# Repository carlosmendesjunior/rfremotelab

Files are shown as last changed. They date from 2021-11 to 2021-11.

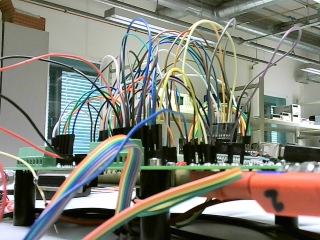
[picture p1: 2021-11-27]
Software/Octave GUI/Figures/frame.png

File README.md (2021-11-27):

# rfremotelab
**RF Remote Laboratory - ReLab**

This is a result of the post-doc of Carlos Mendes Jr. with the research assistance of Lino Van Mulken supported by Rainier van Dommele and idealized by Peter Baltus, all from Eindhoven University of Technology, The Netherlands.

We all hope that this work can help others around the world to disseminate RF laboratory experience among their students from university, college, or school.

We also welcome contributions from everyone! :)

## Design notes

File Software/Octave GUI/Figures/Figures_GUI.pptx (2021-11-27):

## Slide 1

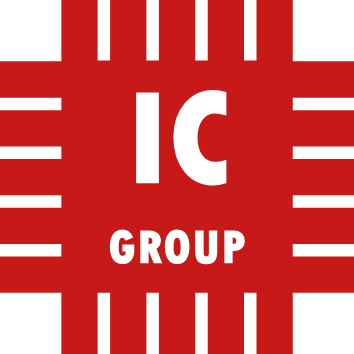
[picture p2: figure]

Figures used in the GUI

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
Integrated Circuits Group – TU/e

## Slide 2

Figures used in the GUI

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
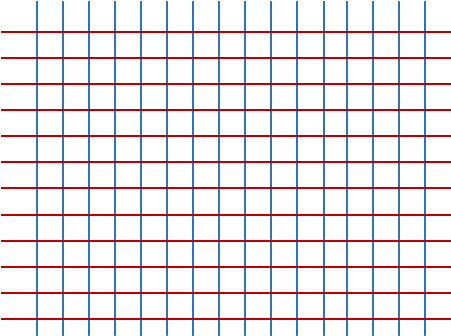
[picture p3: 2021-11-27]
Software/Octave GUI/Figures/Picture1.bmp

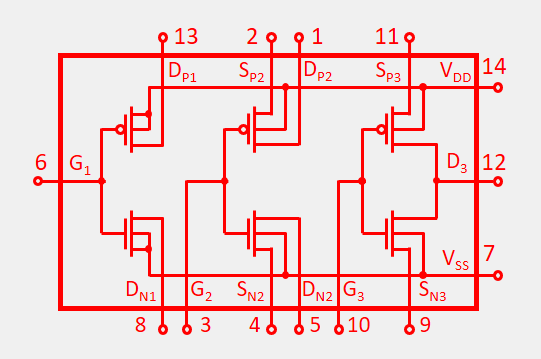
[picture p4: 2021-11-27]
Software/Octave GUI/Figures/CD4007.bmp

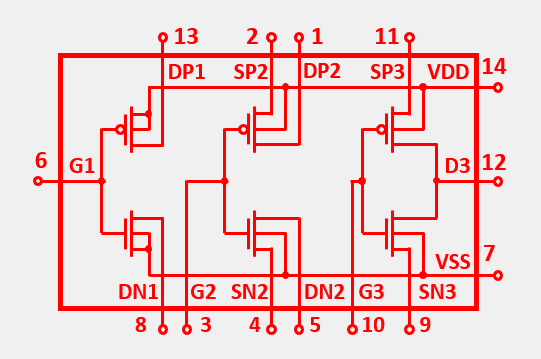
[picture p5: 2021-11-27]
Software/Octave GUI/Figures/CD4007.png

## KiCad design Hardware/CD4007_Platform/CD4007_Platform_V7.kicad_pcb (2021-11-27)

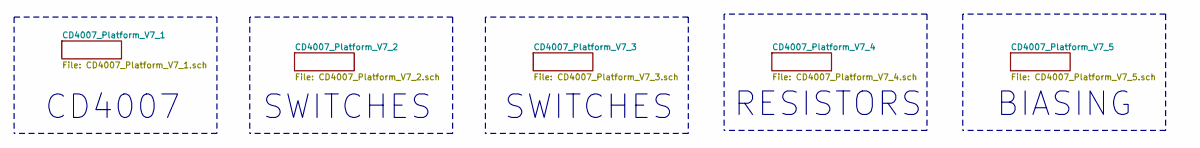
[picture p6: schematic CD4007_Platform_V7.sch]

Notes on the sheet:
CD4007
SWITCHES
SWITCHES
RESISTORS
BIASING

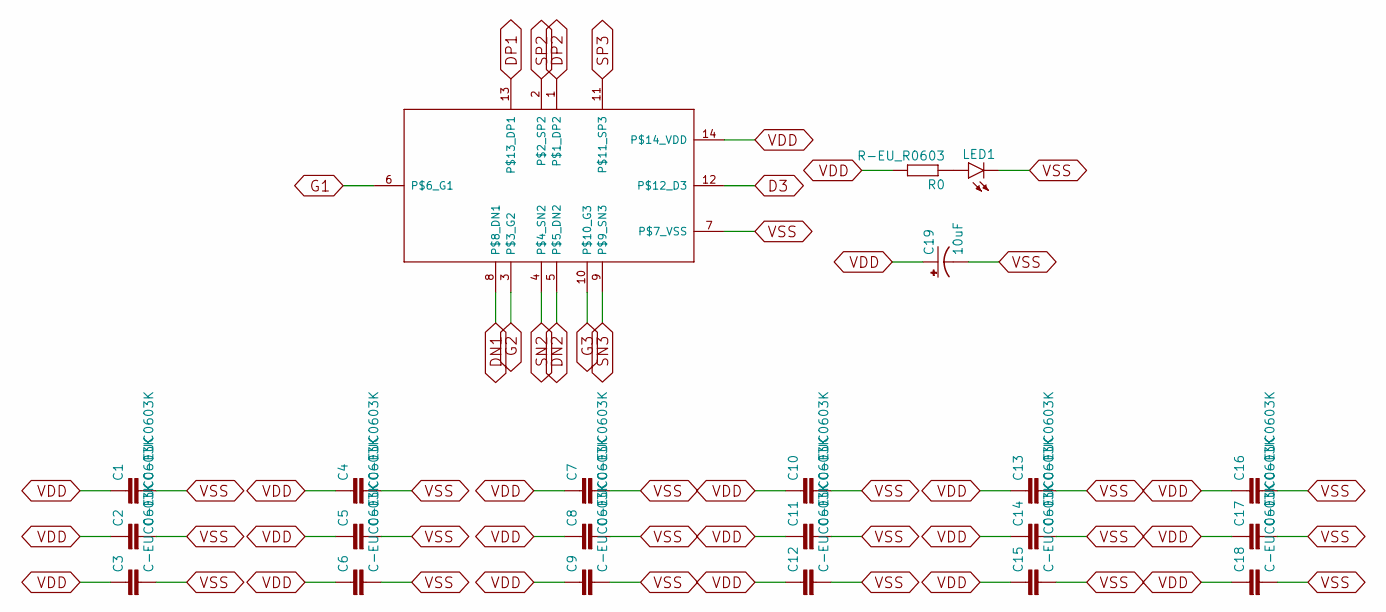
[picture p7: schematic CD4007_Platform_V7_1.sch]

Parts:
C1, C2, C3, C4, C5, C6, C7, C8, C9, C10, C11, C12, C13, C14, C15, C16, C17, C18: C-EUC0603K; C0603K
C19: 10uF; EIA3216
LED1: _T679-?-1E1F1; PLCC2
R0: R-EU_R0603; R0603
U333: CD4007; TSSOP14

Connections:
D3: U333.12 (P$12_D3); also elsewhere on the board
DN1: U333.8 (P$8_DN1); also elsewhere on the board
DN2: U333.5 (P$5_DN2); also elsewhere on the board
DP1: U333.13 (P$13_DP1); also elsewhere on the board
DP2: U333.1 (P$1_DP2); also elsewhere on the board
G1: U333.6 (P$6_G1); also elsewhere on the board
G2: U333.3 (P$3_G2); also elsewhere on the board
G3: U333.10 (P$10_G3); also elsewhere on the board
unnamed: LED1.A, R0.1
SN2: U333.4 (P$4_SN2); also elsewhere on the board
SN3: U333.9 (P$9_SN3); also elsewhere on the board
SP2: U333.2 (P$2_SP2); also elsewhere on the board
SP3: U333.11 (P$11_SP3); also elsewhere on the board
VDD: C1.1, C2.1, C3.1, C4.1, C5.1, C6.1, C7.1, C8.1, C9.1, C10.1, C11.1, C12.1, C13.1, C14.1, C15.1, C16.1, C17.1, C18.1, C19.A (+), R0.2, U333.14 (P$14_VDD); also elsewhere on the board
VSS: C1.2, C2.2, C3.2, C4.2, C5.2, C6.2, C7.2, C8.2, C9.2, C10.2, C11.2, C12.2, C13.2, C14.2, C15.2, C16.2, C17.2, C18.2, C19.C (-), LED1.C, U333.7 (P$7_VSS); also elsewhere on the board

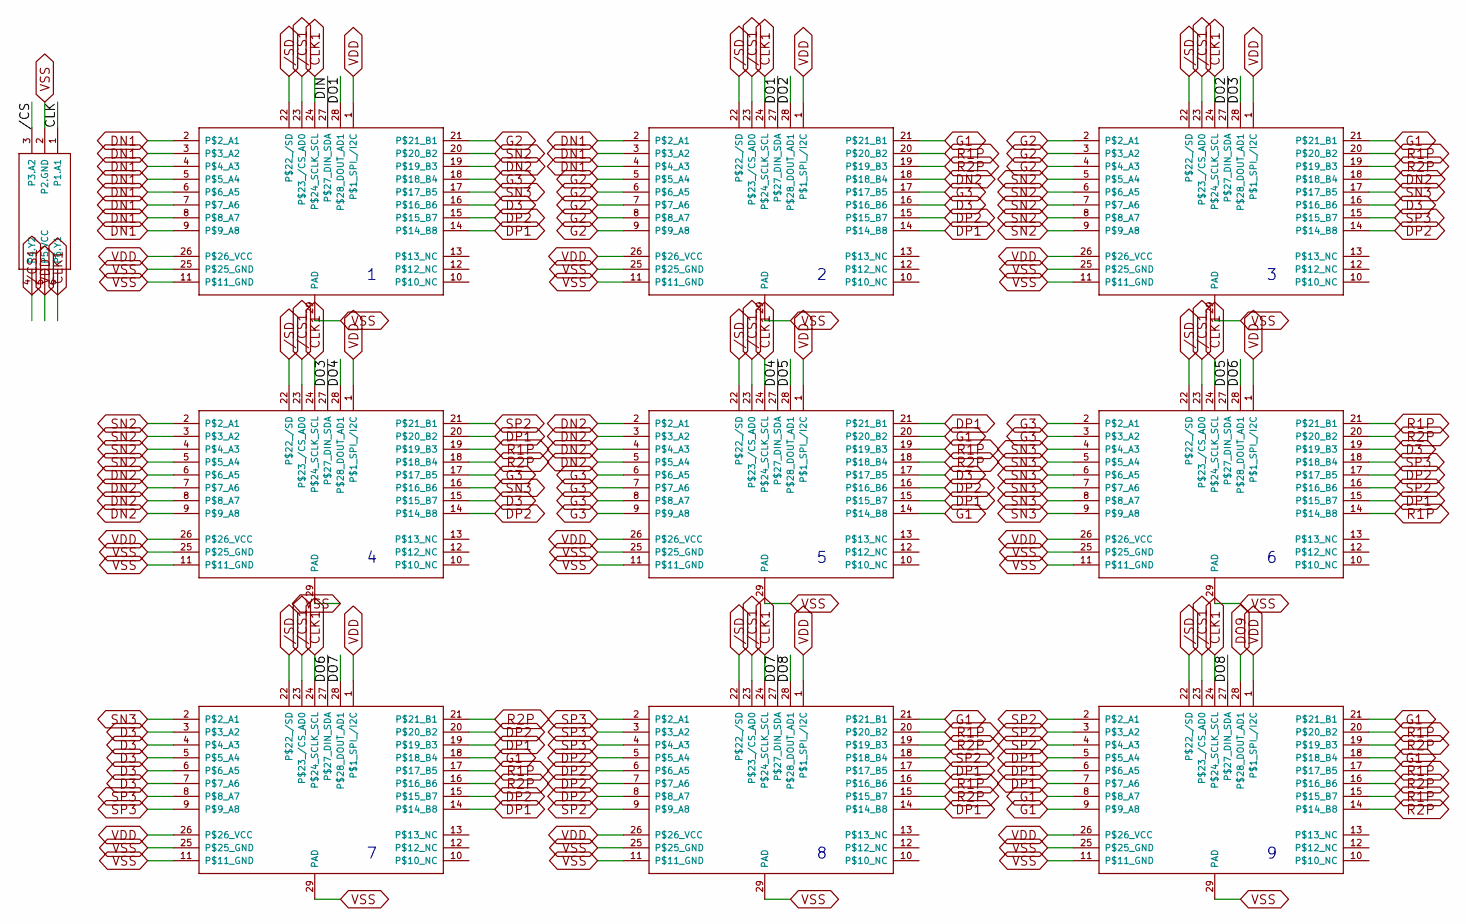
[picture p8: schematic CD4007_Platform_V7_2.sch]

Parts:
U1, U2, U3, U4, U5, U6, U7, U8, U9: MAX14662; QFN-28_UF
U110: 74LVC2G17; SOT363_PHILIPS

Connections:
/CD4007_Platform_V7_2//CS: U110.3 (P3.A2)
/CD4007_Platform_V7_2/CLK: U110.1 (P1.A1)
/CD4007_Platform_V7_2/DIN: U1.27 (P$27_DIN_SDA)
/CD4007_Platform_V7_2/DO1: U1.28 (P$28_DOUT_AD1), U2.27 (P$27_DIN_SDA)
/CD4007_Platform_V7_2/DO2: U2.28 (P$28_DOUT_AD1), U3.27 (P$27_DIN_SDA)
/CD4007_Platform_V7_2/DO3: U3.28 (P$28_DOUT_AD1), U4.27 (P$27_DIN_SDA)
/CD4007_Platform_V7_2/DO4: U4.28 (P$28_DOUT_AD1), U5.27 (P$27_DIN_SDA)
/CD4007_Platform_V7_2/DO5: U5.28 (P$28_DOUT_AD1), U6.27 (P$27_DIN_SDA)
/CD4007_Platform_V7_2/DO6: U6.28 (P$28_DOUT_AD1), U7.27 (P$27_DIN_SDA)
/CD4007_Platform_V7_2/DO7: U7.28 (P$28_DOUT_AD1), U8.27 (P$27_DIN_SDA)
/CD4007_Platform_V7_2/DO8: U8.28 (P$28_DOUT_AD1), U9.27 (P$27_DIN_SDA)
/CS1: U1.23 (P$23_/CS_AD0), U2.23 (P$23_/CS_AD0), U3.23 (P$23_/CS_AD0), U4.23 (P$23_/CS_AD0), U5.23 (P$23_/CS_AD0), U6.23 (P$23_/CS_AD0), U7.23 (P$23_/CS_AD0), U8.23 (P$23_/CS_AD0), U9.23 (P$23_/CS_AD0), U110.4 (P4.Y2); also elsewhere on the board
/SD: U1.22 (P$22_/SD), U2.22 (P$22_/SD), U3.22 (P$22_/SD), U4.22 (P$22_/SD), U5.22 (P$22_/SD), U6.22 (P$22_/SD), U7.22 (P$22_/SD), U8.22 (P$22_/SD), U9.22 (P$22_/SD); also elsewhere on the board
CLK1: U1.24 (P$24_SCLK_SCL), U2.24 (P$24_SCLK_SCL), U3.24 (P$24_SCLK_SCL), U4.24 (P$24_SCLK_SCL), U5.24 (P$24_SCLK_SCL), U6.24 (P$24_SCLK_SCL), U7.24 (P$24_SCLK_SCL), U8.24 (P$24_SCLK_SCL), U9.24 (P$24_SCLK_SCL), U110.6 (P6.Y1); also elsewhere on the board
D3: U1.16 (P$16_B6), U2.16 (P$16_B6), U3.16 (P$16_B6), U4.15 (P$15_B7), U5.17 (P$17_B5), U6.19 (P$19_B3), U7.3 (P$3_A2), U7.4 (P$4_A3), U7.5 (P$5_A4), U7.6 (P$6_A5), U7.7 (P$7_A6); also elsewhere on the board
DN1: U1.2 (P$2_A1), U1.3 (P$3_A2), U1.4 (P$4_A3), U1.5 (P$5_A4), U1.6 (P$6_A5), U1.7 (P$7_A6), U1.8 (P$8_A7), U1.9 (P$9_A8), U2.2 (P$2_A1), U2.3 (P$3_A2), U2.4 (P$4_A3); also elsewhere on the board
DN2: U1.19 (P$19_B3), U2.18 (P$18_B4), U3.18 (P$18_B4), U4.6 (P$6_A5), U4.7 (P$7_A6), U4.8 (P$8_A7), U4.9 (P$9_A8), U5.2 (P$2_A1), U5.3 (P$3_A2), U5.4 (P$4_A3), U5.5 (P$5_A4); also elsewhere on the board
DO9: U9.28 (P$28_DOUT_AD1); also elsewhere on the board
DP1: U1.14 (P$14_B8), U2.14 (P$14_B8), U4.20 (P$20_B2), U5.15 (P$15_B7), U5.21 (P$21_B1), U6.15 (P$15_B7), U7.14 (P$14_B8), U7.19 (P$19_B3), U8.14 (P$14_B8), U8.17 (P$17_B5), U9.5 (P$5_A4), U9.6 (P$6_A5), U9.7 (P$7_A6); also elsewhere on the board
DP2: U1.15 (P$15_B7), U2.15 (P$15_B7), U3.14 (P$14_B8), U4.14 (P$14_B8), U5.16 (P$16_B6), U6.17 (P$17_B5), U7.15 (P$15_B7), U7.20 (P$20_B2), U8.5 (P$5_A4), U8.6 (P$6_A5), U8.7 (P$7_A6), U8.8 (P$8_A7); also elsewhere on the board
G1: U2.21 (P$21_B1), U3.21 (P$21_B1), U5.14 (P$14_B8), U5.20 (P$20_B2), U7.18 (P$18_B4), U8.21 (P$21_B1), U9.8 (P$8_A7), U9.9 (P$9_A8), U9.18 (P$18_B4), U9.21 (P$21_B1); also elsewhere on the board
G2: U1.21 (P$21_B1), U2.5 (P$5_A4), U2.6 (P$6_A5), U2.7 (P$7_A6), U2.8 (P$8_A7), U2.9 (P$9_A8), U3.2 (P$2_A1), U3.3 (P$3_A2), U3.4 (P$4_A3); also elsewhere on the board
G3: U1.18 (P$18_B4), U2.17 (P$17_B5), U4.17 (P$17_B5), U5.6 (P$6_A5), U5.7 (P$7_A6), U5.8 (P$8_A7), U5.9 (P$9_A8), U6.2 (P$2_A1), U6.3 (P$3_A2); also elsewhere on the board
R1P: U2.20 (P$20_B2), U3.20 (P$20_B2), U4.19 (P$19_B3), U5.19 (P$19_B3), U6.14 (P$14_B8), U6.21 (P$21_B1), U7.17 (P$17_B5), U8.16 (P$16_B6), U8.20 (P$20_B2), U9.15 (P$15_B7), U9.17 (P$17_B5), U9.20 (P$20_B2); also elsewhere on the board
R2P: U2.19 (P$19_B3), U3.19 (P$19_B3), U4.18 (P$18_B4), U5.18 (P$18_B4), U6.20 (P$20_B2), U7.16 (P$16_B6), U7.21 (P$21_B1), U8.15 (P$15_B7), U8.19 (P$19_B3), U9.14 (P$14_B8), U9.16 (P$16_B6), U9.19 (P$19_B3); also elsewhere on the board
SN2: U1.20 (P$20_B2), U3.5 (P$5_A4), U3.6 (P$6_A5), U3.7 (P$7_A6), U3.8 (P$8_A7), U3.9 (P$9_A8), U4.2 (P$2_A1), U4.3 (P$3_A2), U4.4 (P$4_A3), U4.5 (P$5_A4); also elsewhere on the board
SN3: U1.17 (P$17_B5), U3.17 (P$17_B5), U4.16 (P$16_B6), U6.4 (P$4_A3), U6.5 (P$5_A4), U6.6 (P$6_A5), U6.7 (P$7_A6), U6.8 (P$8_A7), U6.9 (P$9_A8), U7.2 (P$2_A1); also elsewhere on the board
SP2: U4.21 (P$21_B1), U6.16 (P$16_B6), U8.9 (P$9_A8), U8.18 (P$18_B4), U9.2 (P$2_A1), U9.3 (P$3_A2), U9.4 (P$4_A3); also elsewhere on the board
SP3: U3.15 (P$15_B7), U6.18 (P$18_B4), U7.8 (P$8_A7), U7.9 (P$9_A8), U8.2 (P$2_A1), U8.3 (P$3_A2), U8.4 (P$4_A3); also elsewhere on the board
VDD: U1.1 (P$1_SPI_/I2C), U1.26 (P$26_VCC), U2.1 (P$1_SPI_/I2C), U2.26 (P$26_VCC), U3.1 (P$1_SPI_/I2C), U3.26 (P$26_VCC), U4.1 (P$1_SPI_/I2C), U4.26 (P$26_VCC), U5.1 (P$1_SPI_/I2C), U5.26 (P$26_VCC), U6.1 (P$1_SPI_/I2C), U6.26 (P$26_VCC), U7.1 (P$1_SPI_/I2C), U7.26 (P$26_VCC), U8.1 (P$1_SPI_/I2C), U8.26 (P$26_VCC), U9.1 (P$1_SPI_/I2C), U9.26 (P$26_VCC), U110.5 (P5.VCC); also elsewhere on the board
VSS: U1.11 (P$11_GND), U1.25 (P$25_GND), U1.29 (PAD), U2.11 (P$11_GND), U2.25 (P$25_GND), U2.29 (PAD), U3.11 (P$11_GND), U3.25 (P$25_GND), U3.29 (PAD), U4.11 (P$11_GND), U4.25 (P$25_GND), U4.29 (PAD), U5.11 (P$11_GND), U5.25 (P$25_GND), U5.29 (PAD), U6.11 (P$11_GND), U6.25 (P$25_GND), U6.29 (PAD), U7.11 (P$11_GND), U7.25 (P$25_GND), U7.29 (PAD), U8.11 (P$11_GND), U8.25 (P$25_GND), U8.29 (PAD), U9.11 (P$11_GND), U9.25 (P$25_GND), U9.29 (PAD), U110.2 (P2.GND); also elsewhere on the board

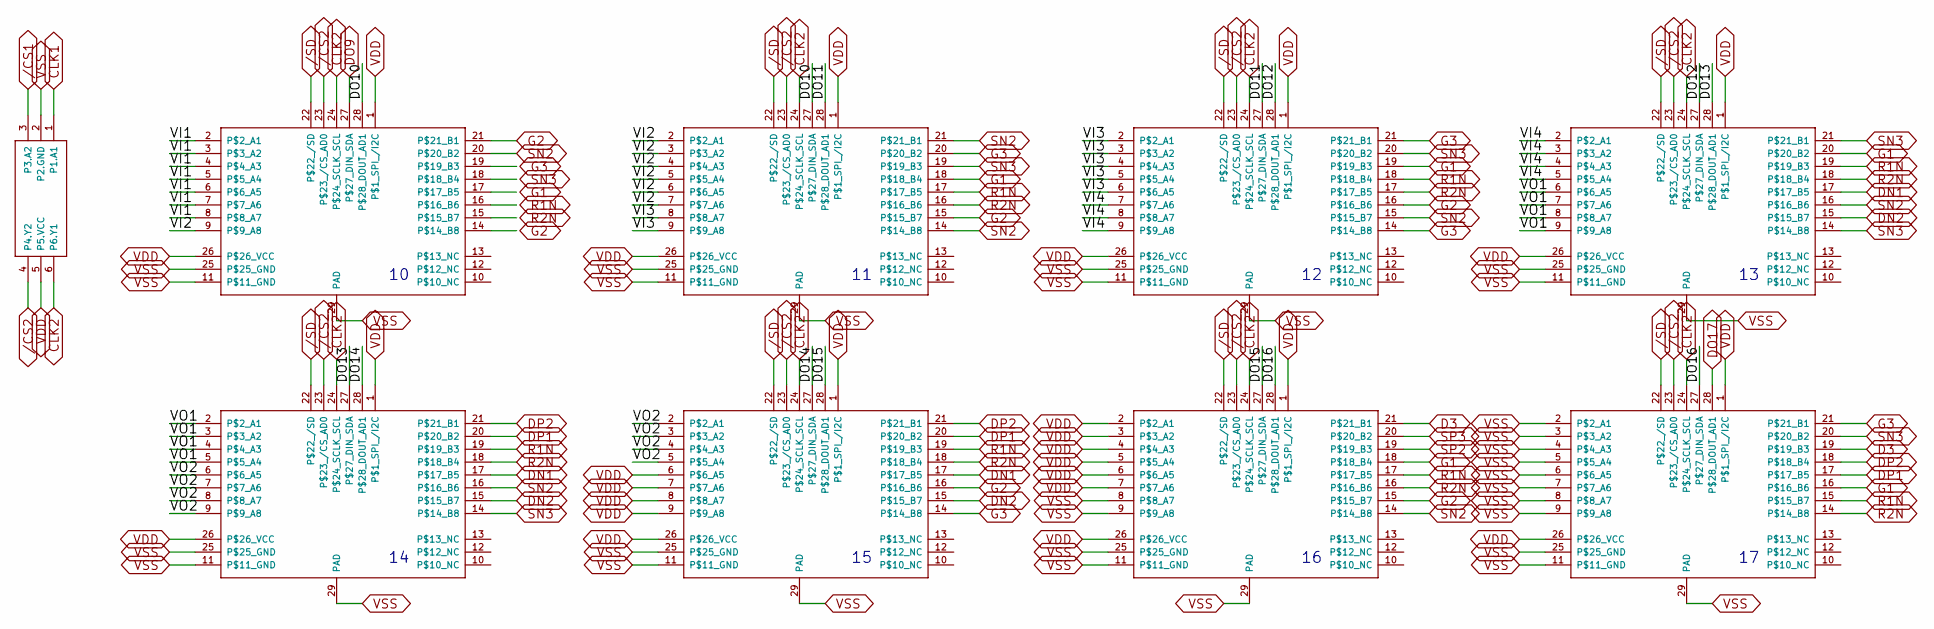
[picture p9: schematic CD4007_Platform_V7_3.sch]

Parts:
U10, U11, U12, U13, U14, U15, U16, U17: MAX14662; QFN-28_UF
U111: 74LVC2G17; SOT363_PHILIPS

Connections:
/CD4007_Platform_V7_3/DO10: U10.28 (P$28_DOUT_AD1), U11.27 (P$27_DIN_SDA)
/CD4007_Platform_V7_3/DO11: U11.28 (P$28_DOUT_AD1), U12.27 (P$27_DIN_SDA)
/CD4007_Platform_V7_3/DO12: U12.28 (P$28_DOUT_AD1), U13.27 (P$27_DIN_SDA)
/CD4007_Platform_V7_3/DO13: U13.28 (P$28_DOUT_AD1), U14.27 (P$27_DIN_SDA)
/CD4007_Platform_V7_3/DO14: U14.28 (P$28_DOUT_AD1), U15.27 (P$27_DIN_SDA)
/CD4007_Platform_V7_3/DO15: U15.28 (P$28_DOUT_AD1), U16.27 (P$27_DIN_SDA)
/CD4007_Platform_V7_3/DO16: U16.28 (P$28_DOUT_AD1), U17.27 (P$27_DIN_SDA)
/CD4007_Platform_V7_3/VI1: U10.2 (P$2_A1), U10.3 (P$3_A2), U10.4 (P$4_A3), U10.5 (P$5_A4), U10.6 (P$6_A5), U10.7 (P$7_A6), U10.8 (P$8_A7)
/CD4007_Platform_V7_3/VI2: U10.9 (P$9_A8), U11.2 (P$2_A1), U11.3 (P$3_A2), U11.4 (P$4_A3), U11.5 (P$5_A4), U11.6 (P$6_A5), U11.7 (P$7_A6)
/CD4007_Platform_V7_3/VI3: U11.8 (P$8_A7), U11.9 (P$9_A8), U12.2 (P$2_A1), U12.3 (P$3_A2), U12.4 (P$4_A3), U12.5 (P$5_A4), U12.6 (P$6_A5)
/CD4007_Platform_V7_3/VI4: U12.7 (P$7_A6), U12.8 (P$8_A7), U12.9 (P$9_A8), U13.2 (P$2_A1), U13.3 (P$3_A2), U13.4 (P$4_A3), U13.5 (P$5_A4)
/CD4007_Platform_V7_3/VO1: U13.6 (P$6_A5), U13.7 (P$7_A6), U13.8 (P$8_A7), U13.9 (P$9_A8), U14.2 (P$2_A1), U14.3 (P$3_A2), U14.4 (P$4_A3), U14.5 (P$5_A4)
/CD4007_Platform_V7_3/VO2: U14.6 (P$6_A5), U14.7 (P$7_A6), U14.8 (P$8_A7), U14.9 (P$9_A8), U15.2 (P$2_A1), U15.3 (P$3_A2), U15.4 (P$4_A3), U15.5 (P$5_A4)
/CS1: U111.3 (P3.A2); also elsewhere on the board
/CS2: U10.23 (P$23_/CS_AD0), U11.23 (P$23_/CS_AD0), U12.23 (P$23_/CS_AD0), U13.23 (P$23_/CS_AD0), U14.23 (P$23_/CS_AD0), U15.23 (P$23_/CS_AD0), U16.23 (P$23_/CS_AD0), U17.23 (P$23_/CS_AD0), U111.4 (P4.Y2); also elsewhere on the board
/SD: U10.22 (P$22_/SD), U11.22 (P$22_/SD), U12.22 (P$22_/SD), U13.22 (P$22_/SD), U14.22 (P$22_/SD), U15.22 (P$22_/SD), U16.22 (P$22_/SD), U17.22 (P$22_/SD); also elsewhere on the board
CLK1: U111.1 (P1.A1); also elsewhere on the board
CLK2: U10.24 (P$24_SCLK_SCL), U11.24 (P$24_SCLK_SCL), U12.24 (P$24_SCLK_SCL), U13.24 (P$24_SCLK_SCL), U14.24 (P$24_SCLK_SCL), U15.24 (P$24_SCLK_SCL), U16.24 (P$24_SCLK_SCL), U17.24 (P$24_SCLK_SCL), U111.6 (P6.Y1); also elsewhere on the board
D3: U16.21 (P$21_B1), U17.19 (P$19_B3); also elsewhere on the board
DN1: U13.17 (P$17_B5), U14.17 (P$17_B5), U15.17 (P$17_B5); also elsewhere on the board
DN2: U13.15 (P$15_B7), U14.15 (P$15_B7), U15.15 (P$15_B7); also elsewhere on the board
DO9: U10.27 (P$27_DIN_SDA); also elsewhere on the board
DO17: U17.28 (P$28_DOUT_AD1); also elsewhere on the board
DP1: U14.20 (P$20_B2), U15.20 (P$20_B2), U17.17 (P$17_B5); also elsewhere on the board
DP2: U14.21 (P$21_B1), U15.21 (P$21_B1), U17.18 (P$18_B4); also elsewhere on the board
G1: U10.17 (P$17_B5), U11.18 (P$18_B4), U12.19 (P$19_B3), U13.20 (P$20_B2), U16.18 (P$18_B4), U17.16 (P$16_B6); also elsewhere on the board
G2: U10.14 (P$14_B8), U10.21 (P$21_B1), U11.15 (P$15_B7), U12.16 (P$16_B6), U15.16 (P$16_B6), U16.15 (P$15_B7); also elsewhere on the board
G3: U10.19 (P$19_B3), U11.20 (P$20_B2), U12.14 (P$14_B8), U12.21 (P$21_B1), U15.14 (P$14_B8), U17.21 (P$21_B1); also elsewhere on the board
R1N: U10.16 (P$16_B6), U11.17 (P$17_B5), U12.18 (P$18_B4), U13.19 (P$19_B3), U14.19 (P$19_B3), U15.19 (P$19_B3), U16.17 (P$17_B5), U17.15 (P$15_B7); also elsewhere on the board
R2N: U10.15 (P$15_B7), U11.16 (P$16_B6), U12.17 (P$17_B5), U13.18 (P$18_B4), U14.18 (P$18_B4), U15.18 (P$18_B4), U16.16 (P$16_B6), U17.14 (P$14_B8); also elsewhere on the board
SN2: U10.20 (P$20_B2), U11.14 (P$14_B8), U11.21 (P$21_B1), U12.15 (P$15_B7), U13.16 (P$16_B6), U14.16 (P$16_B6), U16.14 (P$14_B8); also elsewhere on the board
SN3: U10.18 (P$18_B4), U11.19 (P$19_B3), U12.20 (P$20_B2), U13.14 (P$14_B8), U13.21 (P$21_B1), U14.14 (P$14_B8), U17.20 (P$20_B2); also elsewhere on the board
SP2: U16.19 (P$19_B3); also elsewhere on the board
SP3: U16.20 (P$20_B2); also elsewhere on the board
VDD: U10.1 (P$1_SPI_/I2C), U10.26 (P$26_VCC), U11.1 (P$1_SPI_/I2C), U11.26 (P$26_VCC), U12.1 (P$1_SPI_/I2C), U12.26 (P$26_VCC), U13.1 (P$1_SPI_/I2C), U13.26 (P$26_VCC), U14.1 (P$1_SPI_/I2C), U14.26 (P$26_VCC), U15.1 (P$1_SPI_/I2C), U15.6 (P$6_A5), U15.7 (P$7_A6), U15.8 (P$8_A7), U15.9 (P$9_A8), U15.26 (P$26_VCC), U16.1 (P$1_SPI_/I2C), U16.2 (P$2_A1), U16.3 (P$3_A2), U16.4 (P$4_A3), U16.5 (P$5_A4), U16.6 (P$6_A5), U16.7 (P$7_A6), U16.26 (P$26_VCC), U17.1 (P$1_SPI_/I2C), U17.26 (P$26_VCC), U111.5 (P5.VCC); also elsewhere on the board
VSS: U10.11 (P$11_GND), U10.25 (P$25_GND), U10.29 (PAD), U11.11 (P$11_GND), U11.25 (P$25_GND), U11.29 (PAD), U12.11 (P$11_GND), U12.25 (P$25_GND), U12.29 (PAD), U13.11 (P$11_GND), U13.25 (P$25_GND), U13.29 (PAD), U14.11 (P$11_GND), U14.25 (P$25_GND), U14.29 (PAD), U15.11 (P$11_GND), U15.25 (P$25_GND), U15.29 (PAD), U16.8 (P$8_A7), U16.9 (P$9_A8), U16.11 (P$11_GND), U16.25 (P$25_GND), U16.29 (PAD), U17.2 (P$2_A1), U17.3 (P$3_A2), U17.4 (P$4_A3), U17.5 (P$5_A4), U17.6 (P$6_A5), U17.7 (P$7_A6), U17.8 (P$8_A7), U17.9 (P$9_A8), U17.11 (P$11_GND), U17.25 (P$25_GND), U17.29 (PAD), U111.2 (P2.GND); also elsewhere on the board

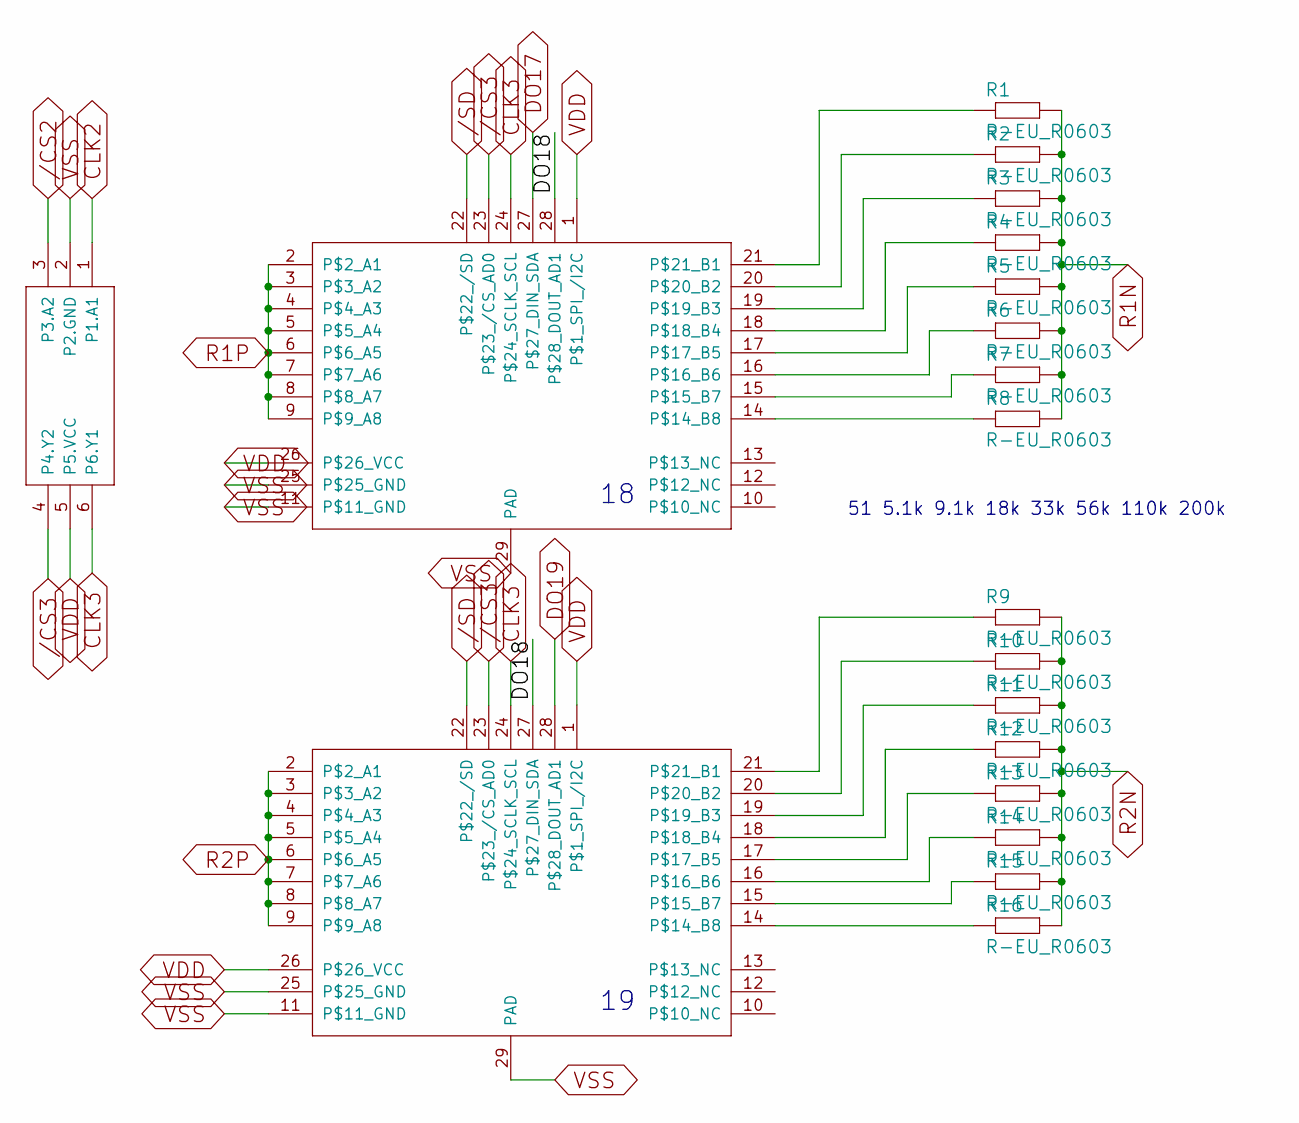
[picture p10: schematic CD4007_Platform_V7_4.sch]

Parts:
R1, R2, R3, R4, R5, R6, R7, R8, R9, R10, R11, R12, R13, R14, R15, R16: R-EU_R0603; R0603
U18, U19: MAX14662; QFN-28_UF
U112: 74LVC2G17; SOT363_PHILIPS

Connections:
/CD4007_Platform_V7_4/DO18: U18.28 (P$28_DOUT_AD1), U19.27 (P$27_DIN_SDA)
/CS2: U112.3 (P3.A2); also elsewhere on the board
/CS3: U18.23 (P$23_/CS_AD0), U19.23 (P$23_/CS_AD0), U112.4 (P4.Y2); also elsewhere on the board
/SD: U18.22 (P$22_/SD), U19.22 (P$22_/SD); also elsewhere on the board
CLK2: U112.1 (P1.A1); also elsewhere on the board
CLK3: U18.24 (P$24_SCLK_SCL), U19.24 (P$24_SCLK_SCL), U112.6 (P6.Y1); also elsewhere on the board
DO17: U18.27 (P$27_DIN_SDA); also elsewhere on the board
DO19: U19.28 (P$28_DOUT_AD1); also elsewhere on the board
unnamed: R1.1, U18.21 (P$21_B1)
unnamed: R2.1, U18.20 (P$20_B2)
unnamed: R3.1, U18.19 (P$19_B3)
unnamed: R4.1, U18.18 (P$18_B4)
unnamed: R5.1, U18.17 (P$17_B5)
unnamed: R6.1, U18.16 (P$16_B6)
unnamed: R7.1, U18.15 (P$15_B7)
unnamed: R8.1, U18.14 (P$14_B8)
unnamed: R9.1, U19.21 (P$21_B1)
unnamed: R10.1, U19.20 (P$20_B2)
unnamed: R11.1, U19.19 (P$19_B3)
unnamed: R12.1, U19.18 (P$18_B4)
unnamed: R13.1, U19.17 (P$17_B5)
unnamed: R14.1, U19.16 (P$16_B6)
unnamed: R15.1, U19.15 (P$15_B7)
unnamed: R16.1, U19.14 (P$14_B8)
R1N: R1.2, R2.2, R3.2, R4.2, R5.2, R6.2, R7.2, R8.2; also elsewhere on the board
R1P: U18.2 (P$2_A1), U18.3 (P$3_A2), U18.4 (P$4_A3), U18.5 (P$5_A4), U18.6 (P$6_A5), U18.7 (P$7_A6), U18.8 (P$8_A7), U18.9 (P$9_A8); also elsewhere on the board
R2N: R9.2, R10.2, R11.2, R12.2, R13.2, R14.2, R15.2, R16.2; also elsewhere on the board
R2P: U19.2 (P$2_A1), U19.3 (P$3_A2), U19.4 (P$4_A3), U19.5 (P$5_A4), U19.6 (P$6_A5), U19.7 (P$7_A6), U19.8 (P$8_A7), U19.9 (P$9_A8); also elsewhere on the board
VDD: U18.1 (P$1_SPI_/I2C), U18.26 (P$26_VCC), U19.1 (P$1_SPI_/I2C), U19.26 (P$26_VCC), U112.5 (P5.VCC); also elsewhere on the board
VSS: U18.11 (P$11_GND), U18.25 (P$25_GND), U18.29 (PAD), U19.11 (P$11_GND), U19.25 (P$25_GND), U19.29 (PAD), U112.2 (P2.GND); also elsewhere on the board

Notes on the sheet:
51 5.1k 9.1k 18k 33k 56k 110k 200k

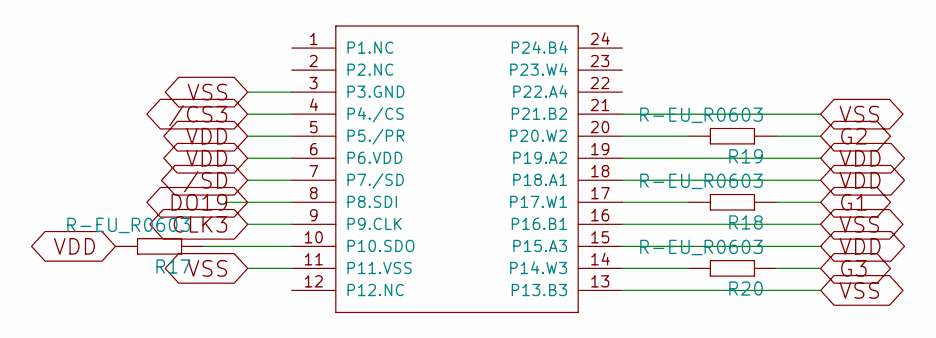
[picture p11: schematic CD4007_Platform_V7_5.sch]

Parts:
R17, R18, R19, R20: R-EU_R0603; R0603
U20: AD5204; TSSOP24

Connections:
/CS3: U20.4 (P4./CS); also elsewhere on the board
/SD: U20.7 (P7./SD); also elsewhere on the board
CLK3: U20.9 (P9.CLK); also elsewhere on the board
DO19: U20.8 (P8.SDI); also elsewhere on the board
G1: R18.1; also elsewhere on the board
G2: R19.1; also elsewhere on the board
G3: R20.1; also elsewhere on the board
unnamed: R17.1, U20.10 (P10.SDO)
unnamed: R18.2, U20.17 (P17.W1)
unnamed: R19.2, U20.20 (P20.W2)
unnamed: R20.2, U20.14 (P14.W3)
VDD: R17.2, U20.5 (P5./PR), U20.6 (P6.VDD), U20.15 (P15.A3), U20.18 (P18.A1), U20.19 (P19.A2); also elsewhere on the board
VSS: U20.3 (P3.GND), U20.11 (P11.VSS), U20.13 (P13.B3), U20.16 (P16.B1), U20.21 (P21.B2); also elsewhere on the board

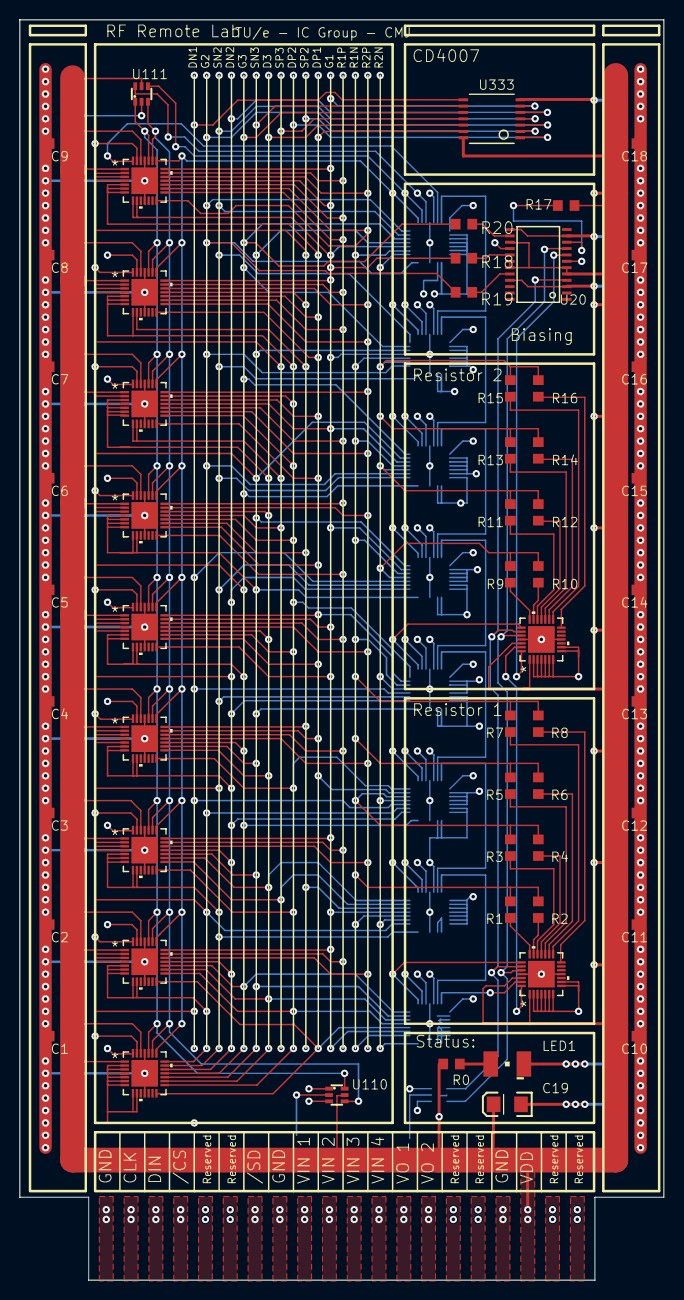
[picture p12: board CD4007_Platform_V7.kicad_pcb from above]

Board: 4 copper layers, 66.0 x 129.1 mm, 65 parts (0 on the bottom side), 71 nets.

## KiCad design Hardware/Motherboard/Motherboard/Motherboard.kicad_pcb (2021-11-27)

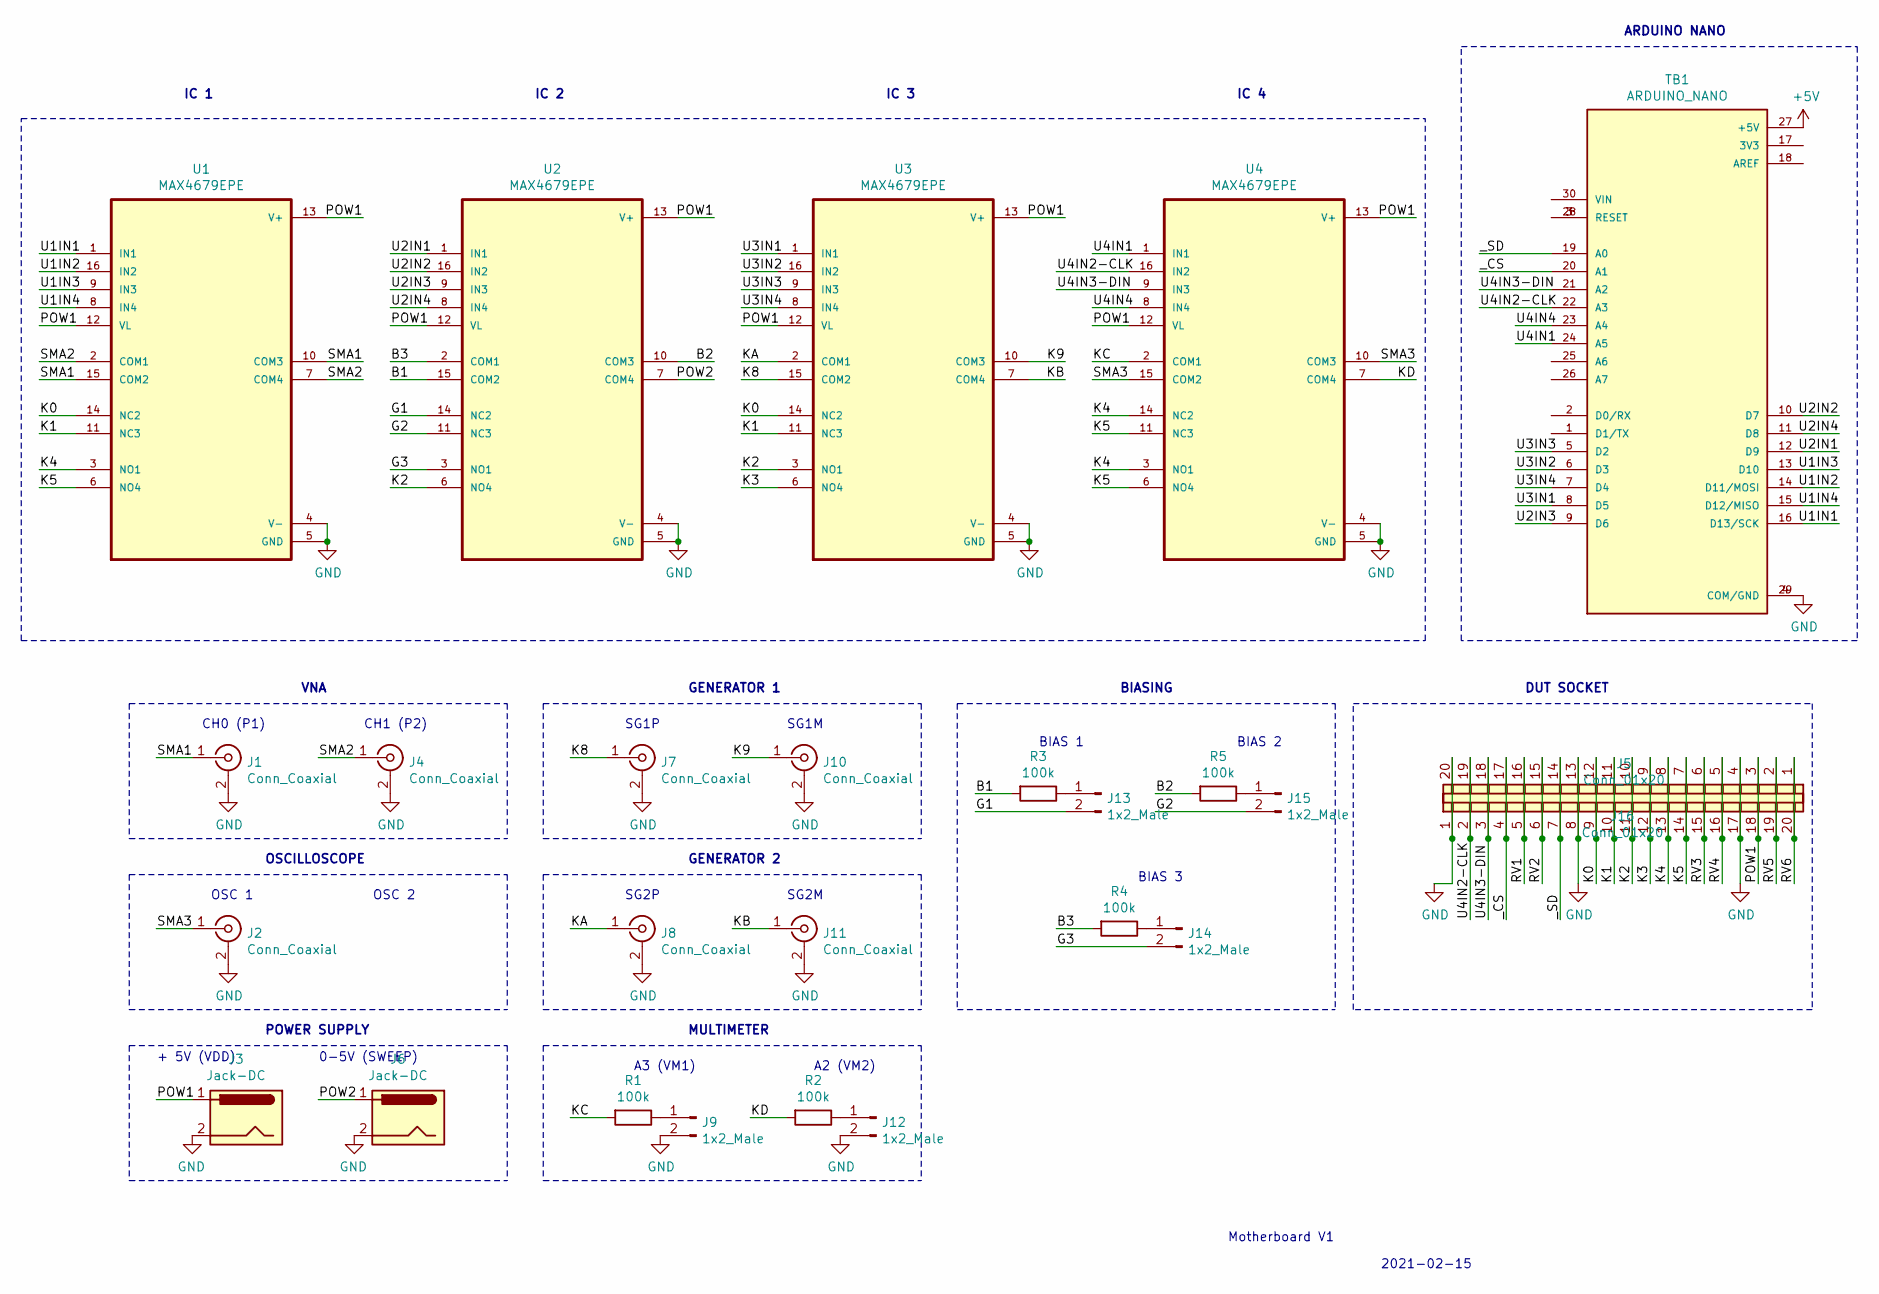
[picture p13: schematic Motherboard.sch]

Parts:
J1, J2, J4, J7, J8, J10, J11: Conn_Coaxial; SMA_Amphenol_132289_EdgeMount
J3, J6: Jack-DC; BarrelJack_Wuerth_6941xx301002
J5, J16: Conn_01x20; PinSocket_1x20_P2.54mm_Vertical
J9, J12, J13, J14, J15: 1x2_Male; PinHeader_1x02_P2.54mm_Vertical
R1, R2, R3, R4, R5: 100k; R_Axial_DIN0207_L6.3mm_D2.5mm_P10.16mm_Horizontal
TB1: ARDUINO_NANO; Arduino_Nano
U1, U2, U3, U4: MAX4679EPE; DIP-16_W7.62mm_LongPads

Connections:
+5V: TB1.27 (+5V)
/B1: R3.2, U2.15 (COM2)
/B2: R5.2, U2.10 (COM3)
/B3: R4.2, U2.2 (COM1)
/G1: J13.2, U2.14 (NC2)
/G2: J15.2, U2.11 (NC3)
/G3: J14.2, U2.3 (NO1)
/K0: J5.9, J16.12, U1.14 (NC2), U3.14 (NC2)
/K1: J5.10, J16.11, U1.11 (NC3), U3.11 (NC3)
/K2: J5.11, J16.10, U2.6 (NO4), U3.3 (NO1)
/K3: J5.12, J16.9, U3.6 (NO4)
/K4: J5.13, J16.8, U1.3 (NO1), U4.3 (NO1), U4.14 (NC2)
/K5: J5.14, J16.7, U1.6 (NO4), U4.6 (NO4), U4.11 (NC3)
/K8: J7.1 (In), U3.15 (COM2)
/K9: J10.1 (In), U3.10 (COM3)
/KA: J8.1 (In), U3.2 (COM1)
/KB: J11.1 (In), U3.7 (COM4)
/KC: R1.2, U4.2 (COM1)
/KD: R2.2, U4.7 (COM4)
/POW1: J3.1, J5.18, J16.3, U1.12 (VL), U1.13 (V+), U2.12 (VL), U2.13 (V+), U3.12 (VL), U3.13 (V+), U4.12 (VL), U4.13 (V+)
/POW2: J6.1, U2.7 (COM4)
/RV1: J5.5, J16.16
/RV2: J5.6, J16.15
/RV3: J5.15, J16.6
/RV4: J5.16, J16.5
/RV5: J5.19, J16.2
/RV6: J5.20, J16.1
/SMA1: J1.1 (In), U1.10 (COM3), U1.15 (COM2)
/SMA2: J4.1 (In), U1.2 (COM1), U1.7 (COM4)
/SMA3: J2.1 (In), U4.10 (COM3), U4.15 (COM2)
/U1IN1: TB1.16 (D13/SCK), U1.1 (IN1)
/U1IN2: TB1.14 (D11/MOSI), U1.16 (IN2)
/U1IN3: TB1.13 (D10), U1.9 (IN3)
/U1IN4: TB1.15 (D12/MISO), U1.8 (IN4)
/U2IN1: TB1.12 (D9), U2.1 (IN1)
/U2IN2: TB1.10 (D7), U2.16 (IN2)
/U2IN3: TB1.9 (D6), U2.9 (IN3)
/U2IN4: TB1.11 (D8), U2.8 (IN4)
/U3IN1: TB1.8 (D5), U3.1 (IN1)
/U3IN2: TB1.6 (D3), U3.16 (IN2)
/U3IN3: TB1.5 (D2), U3.9 (IN3)
/U3IN4: TB1.7 (D4), U3.8 (IN4)
/U4IN1: TB1.24 (A5), U4.1 (IN1)
/U4IN2-CLK: J5.2, J16.19, TB1.22 (A3), U4.16 (IN2)
/U4IN3-DIN: J5.3, J16.18, TB1.21 (A2), U4.9 (IN3)
/U4IN4: TB1.23 (A4), U4.8 (IN4)
/_CS: J5.4, J16.17, TB1.20 (A1)
/_SD: J5.7, J16.14, TB1.19 (A0)
GND: J1.2 (Ext), J2.2 (Ext), J3.2, J4.2 (Ext), J5.1, J5.8, J5.17, J6.2, J7.2 (Ext), J8.2 (Ext), J9.2, J10.2 (Ext), J11.2 (Ext), J12.2, J16.4, J16.13, J16.20, TB1.4 (COM/GND), TB1.29 (COM/GND), U1.4 (V-), U1.5 (GND), U2.4 (V-), U2.5 (GND), U3.4 (V-), U3.5 (GND), U4.4 (V-), U4.5 (GND)
unnamed: J9.1, R1.1
unnamed: J12.1, R2.1
unnamed: J13.1, R3.1
unnamed: J14.1, R4.1
unnamed: J15.1, R5.1
unnamed: TB1.3 (RESET), TB1.28 (RESET)

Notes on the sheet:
2021-02-15
Motherboard V1
VNA
CH0 (P1)
CH1 (P2)
OSCILLOSCOPE
OSC 1
OSC 2
GENERATOR 1
SG1P
SG1M
GENERATOR 2
SG2P
SG2M
MULTIMETER
A3 (VM1)
A2 (VM2)
POWER SUPPLY
+ 5V (VDD)
0-5V (SWEEP)
BIASING
ARDUINO NANO
BIAS 1
BIAS 2
BIAS 3
DUT SOCKET
IC 1
IC 2
IC 3
IC 4

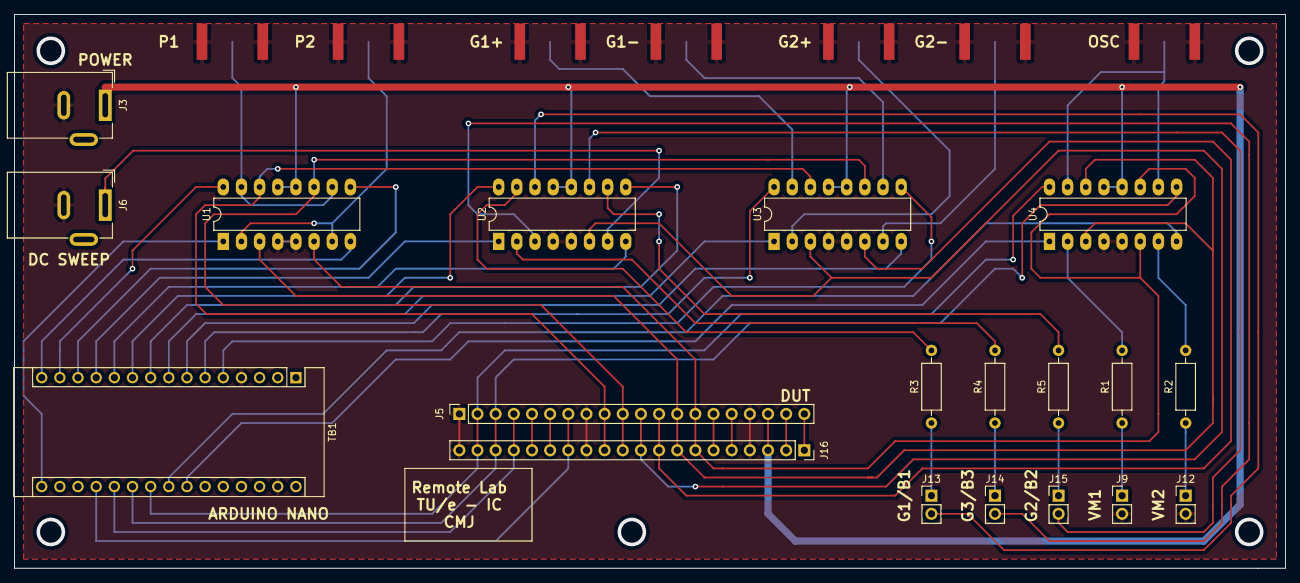
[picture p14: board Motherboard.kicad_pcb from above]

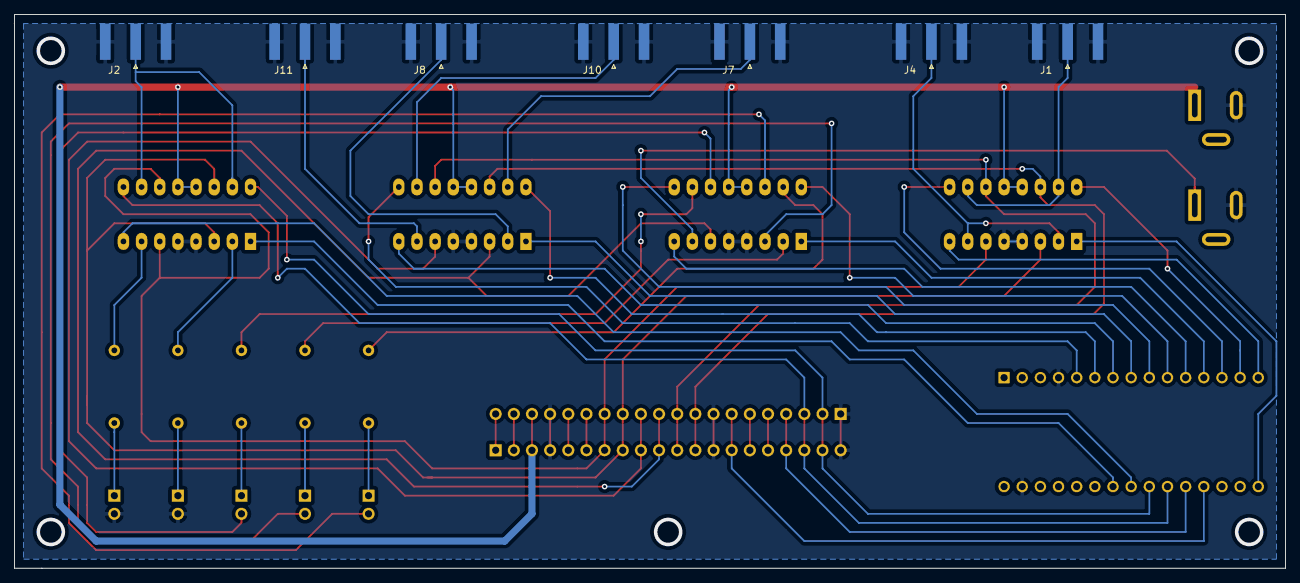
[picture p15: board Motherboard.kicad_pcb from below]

Board: 2 copper layers, 177.8 x 77.5 mm, 26 parts (7 on the bottom side), 54 nets.

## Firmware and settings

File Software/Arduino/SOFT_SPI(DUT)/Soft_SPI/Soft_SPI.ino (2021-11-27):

// Octave to SPI
// Author: Carlos Mendes Junior
// TU/e - IC Group
// Date: 01/Feb/2021
//=================================================================//

#include <SPI.h>

#define EOL 10
#define EOW ' ' 

// Variables Definition
int bit_num = 1000;
int bit_count = 0;
char last_char = EOW;

// Output Pins Definition - DUT
const int clock_SPI = 17;    // A3
const int data_SPI = 16;     // A2
const int enable_SPI = 15;   // A1
const int shutdown_SPI = 14; // A0

// Output Pins Definition - Motherboard
const int pin_mot[] = {13,12,11,10,9,8,7,6,5,4,3,2,19,18,17,16}; // A5,A4,A3,A2

void setup() {

  // Setting Serial Baud
  Serial.begin(9600); 

  // Setting Pin - DUT
  pinMode(clock_SPI, OUTPUT);
  pinMode(data_SPI, OUTPUT);
  pinMode(enable_SPI, OUTPUT);
  pinMode(shutdown_SPI, OUTPUT);

  // Setting Pin - Motherboard
  for (int i = 0; i < 16; i++) {
    pinMode(pin_mot[i], OUTPUT);
  }

  // Reseting Output - Motherboard
  for (int i = 2; i < 16; i=i+4) {
    digitalWrite(pin_mot[i], HIGH);
  }
  for (int i = 3; i < 16; i=i+4) {
    digitalWrite(pin_mot[i], HIGH);
  }

  // Reseting Output - DUT
  digitalWrite(clock_SPI, HIGH);
  digitalWrite(data_SPI, HIGH);
  digitalWrite(enable_SPI, HIGH);
  digitalWrite(shutdown_SPI, HIGH);

  // Wait for PC Initialization
  while (last_char != '/') {
    last_char = get_nextChar();
  };
 
}

//=================================LOOP================================//
void loop() {
  
  // Local Variables
  char cmd;

  cmd = get_nextChar();

  switch (cmd) {
    
    // Get data from Octave and send it (through SPI) to DUT
    case 'd': 
      digitalWrite(clock_SPI, LOW);
      digitalWrite(data_SPI, LOW);
      delay(4);
      digitalWrite(enable_SPI, LOW);
      while ( (bit_count < bit_num) && (last_char != EOW) ){
        last_char = get_nextChar();
        switch (last_char){
          case '0':
            digitalWrite(data_SPI, LOW);
            clock_out();
            bit_count++;
            signal_octave();
            break;
          case '1':
            digitalWrite(data_SPI, HIGH);
            clock_out();
            bit_count++;
            signal_octave();
            break;
          default:
            //last_char = EOW;
            break;
        }
      }
      signal_octave(); // THIS WAS ADDED
      digitalWrite(enable_SPI, HIGH);
      delay(4);
      digitalWrite(clock_SPI, HIGH);
      digitalWrite(data_SPI, HIGH);
      bit_count = 0;
      last_char = EOL;
      break;
      
    // --> Get data from Octave and send it (through Parallel) to the Motherboard 
    case 'm': 
      while ( (bit_count < bit_num) && (last_char != EOW) ){
        last_char = get_nextChar();
        switch (last_char){
          case '0':
            digitalWrite(pin_mot[bit_count], LOW);
            bit_count++;
            signal_octave();
            break;
          case '1':
            digitalWrite(pin_mot[bit_count], HIGH);
            bit_count++;
            signal_octave();
            break;
          default:
            //last_char = EOW;
            break;
        }
      }
      signal_octave(); // THIS WAS ADDED
      bit_count = 0;
      last_char = EOL;
      break;
      
    case EOL: // discard EOLs
      // Do nothing
      break;
      
    case EOW:   // discard end of word
      // Do nothing
      break;
      
    default:  // What the bleep?
      break;
  }
}

//=============================FUNCTIONS===============================//

char get_nextChar() {
  while (!Serial.available()) {};
  return (Serial.read());
}

void data_out(char data, int pin) {
  if (data == '0'){
    digitalWrite(pin, LOW);
  }
  else if (data == '1'){
    digitalWrite(pin, HIGH);
  }
  else{
    // Do nothing
  }
}

void clock_out(void) {
  delay(2); 
  digitalWrite(clock_SPI, HIGH);
  delay(2);
  digitalWrite(clock_SPI, LOW);
}

void signal_octave(void){
  Serial.write('c');
}

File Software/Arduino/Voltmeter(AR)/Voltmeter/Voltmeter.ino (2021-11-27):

// Octave to SPI
// Author: Carlos Mendes Junior
// TU/e - IC Group
// Date: 01/Feb/2021
//=================================================================//

#include <SPI.h>
#include "Wire.h"

#define EOL 10
#define EOW ' '

// Variable Definition - Communication
int bit_num = 1000;
int bit_count = 0;
char last_char = EOW;
char buffer1[10];
char buffer2[10];
char buffer3;

// Output Pins Definition - Attenuator
int pin_le = 3;
int pin_clk = 4;
int pin_data = 2;

void setup() {

  // Setting Serial Baud
  Serial.begin(9600);

  // Wait for PC Initialization
  while (last_char != '/') {
    last_char = get_nextChar();
  };

}

//=================================LOOP================================//
void loop() {

  // Local Variables
  char cmd;

  cmd = get_nextChar();

  switch (cmd) {

    // --> Get data from Octave and send it to the ADC (Voltmeter)
    case 'v':
      while ( (bit_count < bit_num) && (last_char != EOW) ) {
        last_char = get_nextChar();
        if (last_char != EOL && last_char != EOW) {
          buffer3 = last_char;
          signal_octave();
        }
      }
      signal_octave();
      voltmeter(buffer3);
      bit_count = 0;
      last_char = EOL;
      break;

    case EOL: // discard EOLs
      // Do nothing
      break;

    case EOW:   // discard end of word
      // Do nothing
      break;

    default:  // What the bleep?
      break;
  }
  
}

//=============================FUNCTIONS===============================//

char get_nextChar() {
  while (!Serial.available()) {};
  return (Serial.read());
}

void signal_octave(void) {
  Serial.write('c');
}

void voltmeter(char p) {
  unsigned int v; // 
  switch (p) {
    case '0':
      pinMode(A0, INPUT);
      v = analogRead(A0);
      break;
    case '1':
      pinMode(A1, INPUT);
      v = analogRead(A1);
      break;
    case '2':
      pinMode(A2, INPUT);
      v = analogRead(A2);
      break;
    case '3':
      pinMode(A3, INPUT);
      v = analogRead(A3);
      break;
    case '4':
      pinMode(A4, INPUT);
      v = analogRead(A4);
      break;
    case '5':
      pinMode(A5, INPUT);
      v = analogRead(A5);
      break;
    default:
      // Do nothing
      break;
  }
  Serial.print(v);
//  itoa(v, v_c, 5);
//  Serial.write(v_c[0]);
//  Serial.write(v_c[1]);
//  Serial.write(v_c[2]);
//  Serial.write(v_c[3]);
  //Serial.write('c');
}
